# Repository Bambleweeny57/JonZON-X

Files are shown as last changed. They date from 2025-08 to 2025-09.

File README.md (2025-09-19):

# 🎵 JonZON-X AY-3-8910 Sound Expansion for ZX81

JonZON-X is a modern recreation of the ZON-X-81 Sound Box by Bi-Pak, designed for the ZX81. It uses the AY-3-8910 Programmable Sound Generator (PSG) and supports stereo line-out, optional multi-PSG expansion, and historically accurate address decoding.

This project prioritizes:
- ✅ Robust signal integrity
- ✅ Accurate control logic
- ✅ Modular expansion
- ✅ Historical preservation

---

## 🎯 Goals

- Recreate the original ZON-X-81 using AY-3-8910 (not AY-3-8912)
- Provide stereo line-out instead of onboard speaker
- Divide CPU clock as in the original design
- Support optional second and third PSGs via A5 and A6
- Document logic blocks and truth tables that match the actual schematic

---

## 🧠 Control Signal Logic

JonZON-X uses modern 74HC-series gates to derive control signals for the AY-3-8910. The address decoding is based on:

- **A0–A4**: Select the first PSG
- **A5**: Optional second PSG (replaces A4)
- **A6**: Optional third PSG (replaces A4)
- **A7**: Used in BC1 logic
- **/IOREQ**, **/WR**, **/RD**: Control timing

### Signal Derivation

| Signal | Logic Expression | Gates Used |
|---|---|---|
| **BDIR** | Derived from /IOREQ and /WR  
→ Routed through 74HC02 (inversion), 74HC08 (AND), and 74HC11 (3-input AND) | 74HC02, 74HC08, 74HC11 |
| **BC1** | Derived from /IOREQ, /WR, A2, A7, /RD  
→ Routed through 74HC02, 74HC08, and 74HC11 | 74HC02, 74HC08, 74HC11 |

There is **no AYSEL signal**—address selection is handled directly via A0–A4 (or A5/A6 for additional PSGs).

---

## 📊 Truth Table

| A0–A4 | A5/A6 | A2 | A7 | /IOREQ | /WR | /RD | BDIR | BC1 | Operation |
|---|---|----|----|---|-----|-----|---|-----|---|
| PSG 1 selected | — | 1  | 1  | 0 | 0 | 1 | 1 | 1 | Write to register |
| PSG 1 selected | — | 1  | 1  | 0 | 0 | 0 | 1 | 0 | Write to PSG |
| PSG 1 selected | — | 1  | 1  | 0 | 1 | 0 | 0 | 1 | Read from PSG |
| PSG 2 selected | A5=1  | 1  | 1  | 0 | — | — | — | — | Optional second PSG |
| PSG 3 selected | A6=1  | 1  | 1  | 0 | — | — | — | — | Optional third PSG |
| Not selected | — | —  | —  | — | — | — | 0 | 0 | Inactive |

---

## 🖼️ Visual Decode Logic

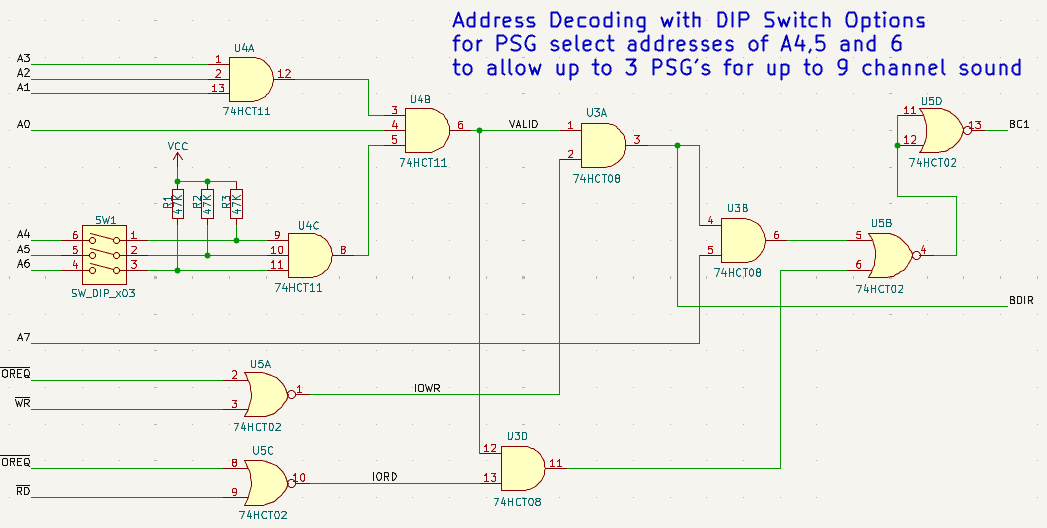
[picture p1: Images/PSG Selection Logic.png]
AY Control Logic


This schematic snippet shows how BDIR and BC1 are generated using 74HC02, 74HC08, and 74HC11 gates. Address selection is handled via A0–A4 (or A5/A6 for additional PSGs).

---

## 🎚️ DIP Switch Mapping for PSG Selection

JonZON-X supports up to three AY-3-8910 PSGs using configurable address lines via DIP switches. The DIP switches control A4, A5, and A6 to select which PSG is active.

| PSG | A4 | A5 | A6 | Address (Binary) | Address (Decimal) |
|---|----|----|----|---|---|
| PSG1  | 1  | 0  | 0  | `11111111` | 255 |
| PSG2  | 0  | 1  | 0  | `11101111` | 239 |
| PSG3  | 0  | 0  | 1  | `11011111` | 223 |

- **A4, A5, A6** are mutually exclusive: only one should be active at a time.
- These bits are part of the PSG register select address.
- DIP switches override the default A4–A6 lines from the ZX81.

This mapping allows users to select which PSG responds to register writes, enabling multi-chip expansion and stereo mixing.

---

## 📚 Historical References

- [ZON-X-81 Archive (1982 Bi-Pak)](https://archive.org/details/ZON_X-81_1982_Bi-Pak_GB)
- [RevSpace ZX81 PSG Expansion](https://revspace.nl/Zon_ZX-81_Programmable_Sound_Generator_expansion_for_ZX81PLUS35_with_working_SD-Card)
- [Mahjongg2 ZON-Compatible PSG](https://github.com/mahjongg2/ZON-compatible-PSG-with-SD-interface-for-ZX81plus35-ZX81)
- [Micromusic Article](https://www.muzines.co.uk/articles/micromusic/4456)
- [ZX8081 Clone Log](https://hackaday.io/project/184361-zx8081-homebrew-clone/log/203915-my-project-log-jan-mar2021)

---

## 🛠️ Future Plans

If the initial revision works, future additions may include:
- RAM and ROM expansion
- Joystick port
- Enhanced stereo mixing

---

### 🧪 Test 1: Test Routine

```basic
10 REM ZONTEST1
20 LET A=16514
30 POKE A,62
40 LET A=A+1
50 POKE A,0
60 LET A=A+1
70 POKE A,211
80 LET A=A+1
90 POKE A,0
100 LET A=A+1
110 POKE A,201
120 POKE 16515,7
130 POKE 16516,255
140 RAND USR 16514
150 POKE 16515,8
160 POKE 16516,191
170 RAND USR 16514
180 POKE 16515,13
190 POKE 16516,9
200 RAND USR 16514
210 GOTO 210
```
- 🔊 ZONTEST1 – Basic Tone Setup: [zontest1.p](https://github.com/jgratton72/JonZON-X/blob/master/Tests/zontest1.p)

### 🧪 Test 2: Envelope & Stereo Test

```basic
10 REM ZONTEST2
20 LET A=16514
30 POKE A,62
40 LET A=A+1
50 POKE A,0
60 LET A=A+1
70 POKE A,211
80 LET A=A+1
90 POKE A,0
100 LET A=A+1
110 POKE A,201
120 POKE 16515,7
130 POKE 16516,255
140 RAND USR 16514
150 POKE 16515,8
160 POKE 16516,191
170 RAND USR 16514
180 POKE 16515,13
190 POKE 16516,9
200 RAND USR 16514
210 LET E=0
220 POKE 16515,13
230 POKE 16516,E
240 RAND USR 16514
250 LET I=0
260 LET I=I+1
270 IF I<1000 THEN GOTO 260
280 LET E=E+1
290 IF E<16 THEN GOTO 220
300 GOTO 210
```
- 🎛️ ZONTEST2 – Envelope & Stereo: [zontest2.p](https://github.com/jgratton72/JonZON-X/blob/master/Tests/zontest2.p)

### 🧪 Test 3: Envelope Period Sweep

```basic
10 REM ZONTEST3
20 LET A=16514
30 POKE A,62
40 LET A=A+1
50 POKE A,0
60 LET A=A+1
70 POKE A,211
80 LET A=A+1
90 POKE A,0
100 LET A=A+1
110 POKE A,201
120 POKE 16515,7
130 POKE 16516,255
140 RAND USR 16514
150 POKE 16515,8
160 POKE 16516,191
170 RAND USR 16514
180 POKE 16515,13
190 POKE 16516,9
200 RAND USR 16514
210 LET P=0
220 POKE 16515,11
230 POKE 16516,P
240 RAND USR 16514
250 POKE 16515,12
260 POKE 16516,0
270 RAND USR 16514
280 LET I=0
290 LET I=I+1
300 IF I<1000 THEN GOTO 290
310 LET P=P+16
320 IF P<256 THEN GOTO 220
330 GOTO 210
```
- 📈 ZONTEST3 – Envelope Sweep: [zontest3.p](https://github.com/jgratton72/JonZON-X/blob/master/Tests/zontest3.p)

### 🧪 Test 4: DIP-Selectable PSG Verification

```basic
10 REM ZONTEST4
20 LET A=16514
30 POKE A,62
40 LET A=A+1
50 POKE A,0
60 LET A=A+1
70 POKE A,211
80 LET A=A+1
90 POKE A,0
100 LET A=A+1
110 POKE A,201
120 POKE 16515,8
130 POKE 16516,255
140 RAND USR 16514
150 LET I=0
160 LET I=I+1
170 IF I<500 THEN GOTO 160
180 POKE 16515,8
190 POKE 16516,239
200 RAND USR 16514
210 LET I=0
220 LET I=I+1
230 IF I<500 THEN GOTO 220
240 POKE 16515,8
250 POKE 16516,223
260 RAND USR 16514
270 LET I=0
280 LET I=I+1
290 IF I<500 THEN GOTO 280
300 GOTO 120
```
- 🎚️ ZONTEST4 – DIP-Selectable PSGs: [zontest4.p](https://github.com/jgratton72/JonZON-X/blob/master/Tests/zontest4.p)

---

## 📅 Revision History

### 🔧 Rev 1.0 Testing Note — Stereo Jack Adaptation
- **Socket Type:** 3-pin stereo jacks used in place of shunted 5-pin variants.
- **Pad Bridging:** Inner pads manually jumped to outer signal pads; ground positioned at center front.
- **Trade-off:** Left and Right channels will be reversed — acceptable for initial validation.
- **Rationale:** Simplifies early testing without requiring shunt headers. Prioritizes proof-of-function over stereo fidelity

### 🔄 Rev 1.1 — Audio Jack Correction
- **Issue:** Left and Right channels were misrouted via Shunts A and B.
- **Fix:** Channel A and B were reversed in the schematic to compensate for the physical swap.
- **Impact:** Stereo output now matches expected channel mapping. Updated KiCad files reflect this correction.

### 🔄 Rev 1.2 – Stereo Output Mapping Adjustment

- **Issue**: Legacy ZON-X-81 software frequently routes noise to Channel B, but JonZON-X previously mixed Channel C to both outputs (a common pattern in other PSG devices, including the ZX Spectrum 128K). This caused noise effects to be isolated to the right channel or lost in stereo playback.
- **Fix**: Remapped stereo output:
  - Channel A → Left
  - Channel B → Mixed (Left + Right)
  - Channel C → Right  
  This ensures Channel B (the legacy noise channel) is centered in stereo output.
- **Impact**: Improved compatibility with original ZON-X-81 programs and demos. Noise effects now play as intended across both channels, preserving the sonic balance of legacy software.

[]()

### 🔄 Rev 1.3 – Logic Footprint Correction
- **Issue**: 74HTC Logic IC footprints where set as 400mil wide not 300mil.
- **Fix**: Change footprints:
  - Corrected 74HCT logic IC footprints from 400mil to 300mil for proper socket fit.
  - Updated KiCad symbols and PCB layout to reflect accurate DIP sizing.
- **Impact**: Improves build reliability and simplifies future revisions.

### 🔄 Rev 1.4 – Dual PSG Support & Expansion-Ready Logic

- 🧩 **Added AY-3-8912 schematic symbol** to Rev 1.3 base, enabling direct support for legacy demos and stereo output
- 🧠 **Dual PSG compatibility**: Supports both AY-3-8910 and AY-3-8912 via shared footprint and modular decoding logic
- 🧰 **Decoding logic updated** to include `/RD` line—reserved for future expansion (e.g. SD card interfacing via Port A)
- 🛠️ **Maintains Rev 1.3 write logic** for AY-3-8910 while enabling seamless upgrade path to AY-3-8912
- 🎶 **Verified compatibility** with original ULA and both HCT and F-series logic—multi scroll and Viaduct demos pass cleanly with AY-3-8912
- ⚠️ **VLA81 compatibility issues noted**: Viaduct demo fails to run reliably due to timing sensitivity and address decoding quirks. Detaching A15 improves behavior in some cases but does not fully resolve playback issues. Original ULA remains the recommended option for stable demo performance.
- 📘 **README and onboarding overlays updated** to reflect dual-chip support and future expansion notes

[]()

> Rev 1.4 preserves the modular ethos of JonZON-X while enabling legacy fidelity and future-proofed decoding. Component back-mounting and through-hole edge connector support are planned for a future revision.

---

## 🧩 Rev1.x Closure Summary

The Rev1.x series of JONZON-X-81 boards concludes with **Rev1.4**, marking the final iteration of this foundational phase. Throughout development, multiple configurations were explored to optimize PSG register selection and compatibility:

- **AY-3-8910** with grounded Port B showed partial success in register selection, but inconsistencies remained—especially when paired with **74F logic**.
- Transitioning to **AY-3-8912** and **74HCT logic** yielded flawless register selection across demo routines, confirming a stable configuration.

Based on these findings, Rev1.4 is the final release in the Rev1.x lineage. All future development will pivot to **Rev2.0**, which will:

- Standardize on the **AY-3-8912** sound chip.
- Feature **back-mounted components** for cleaner top-side access.
- Introduce a **through-hole edge connector** to support future expansions.
- Include a **development header** exposing A0–A7, 5V, and GND—enabling both sound card interfacing and SD card experimentation via Port A.

Documentation for Rev1.x will remain available for reference and legacy compatibility. Contributors are encouraged to migrate to the Rev2.0 repo for ongoing development and community collaboration.

---

## 📝 Notes

This is my first KiCad project and GitHub repo. While I’ve used other EDA tools and GitHub before, this is a learning curve and a preservation effort.

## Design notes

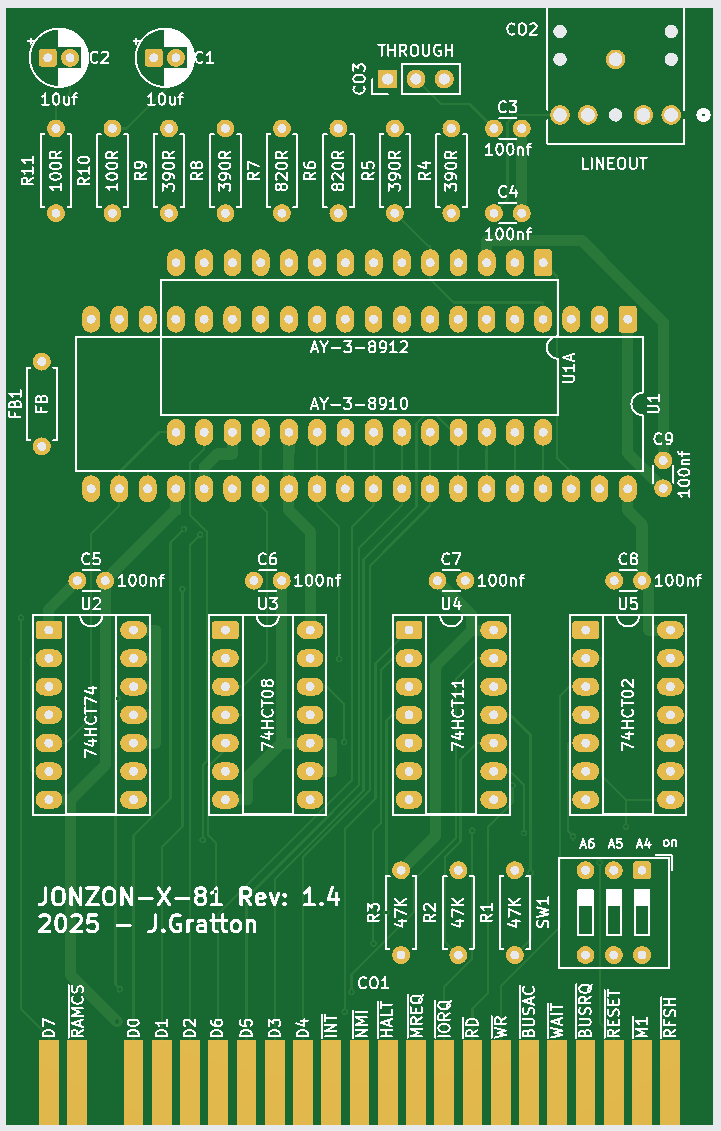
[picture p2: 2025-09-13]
Images/Gerber Top.png

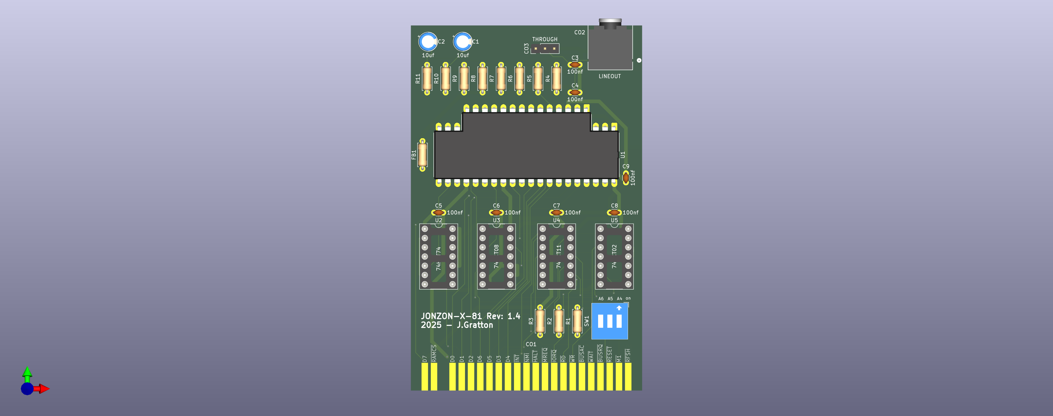
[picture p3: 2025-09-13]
Images/MyZON-X Top.png

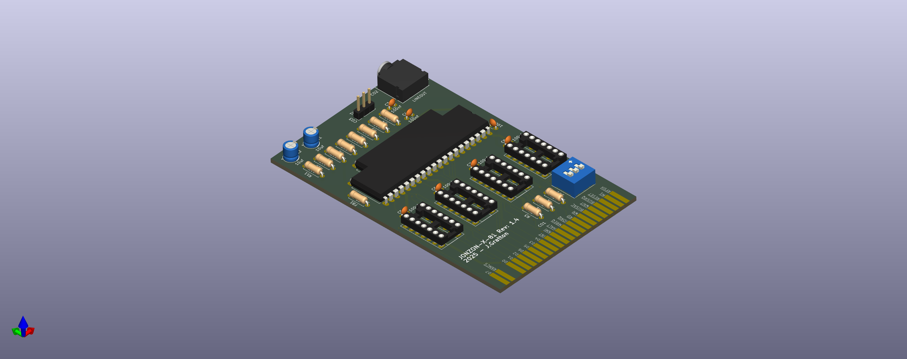
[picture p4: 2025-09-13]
Images/JONZON-X-81 Angled.png

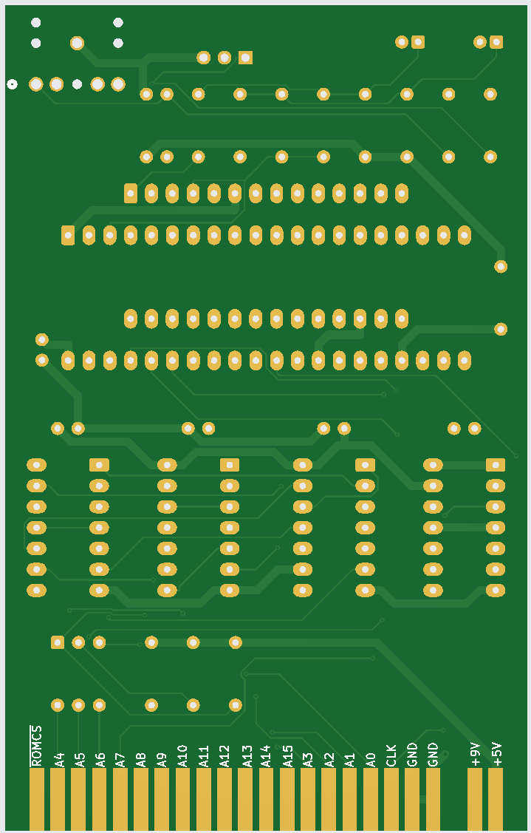
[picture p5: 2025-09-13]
Images/Gerber Bottom.png

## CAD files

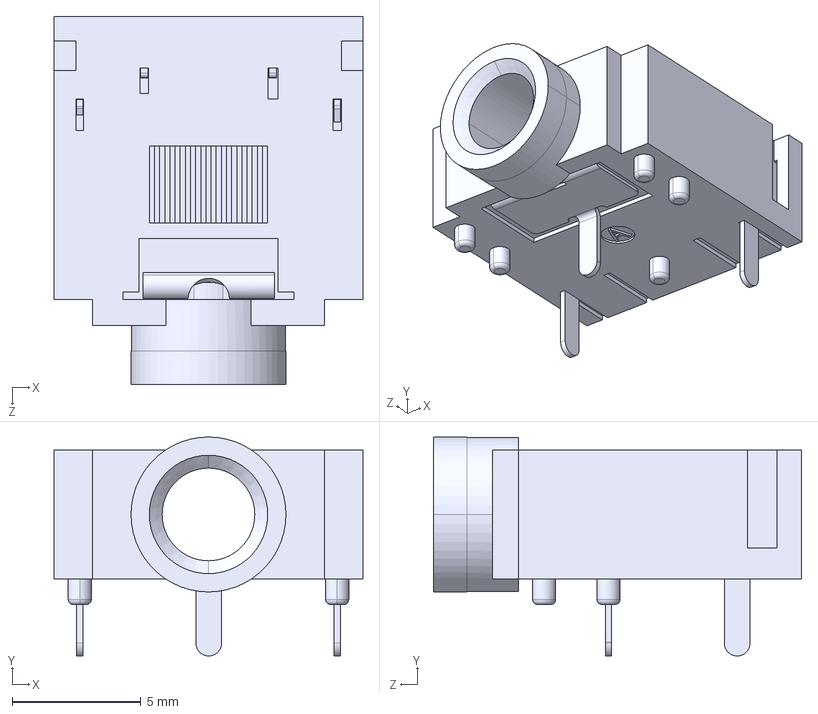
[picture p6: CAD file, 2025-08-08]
Stereo Jack/SJ1-3523N--3DModel-STEP-1.STEP
12.0 x 8.51 x 14.3 mm

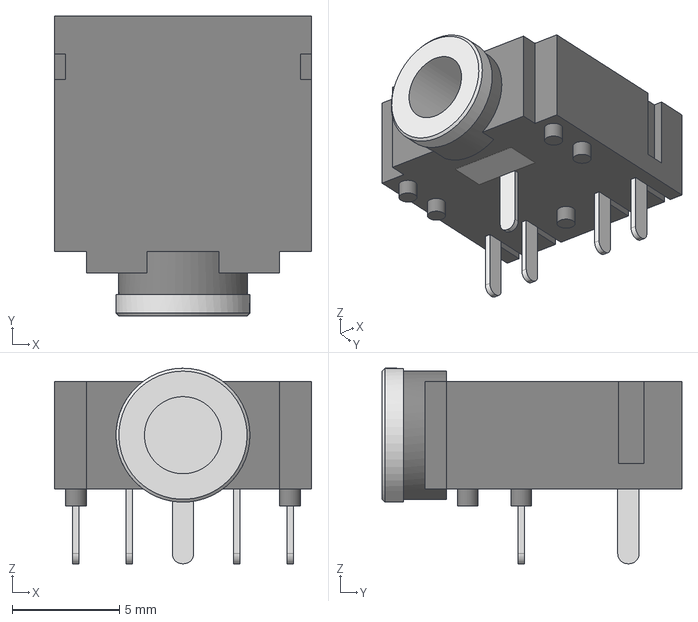
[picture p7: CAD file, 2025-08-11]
Stereo Jack/SPC21348.stp
12.0 x 14.0 x 9.13 mm

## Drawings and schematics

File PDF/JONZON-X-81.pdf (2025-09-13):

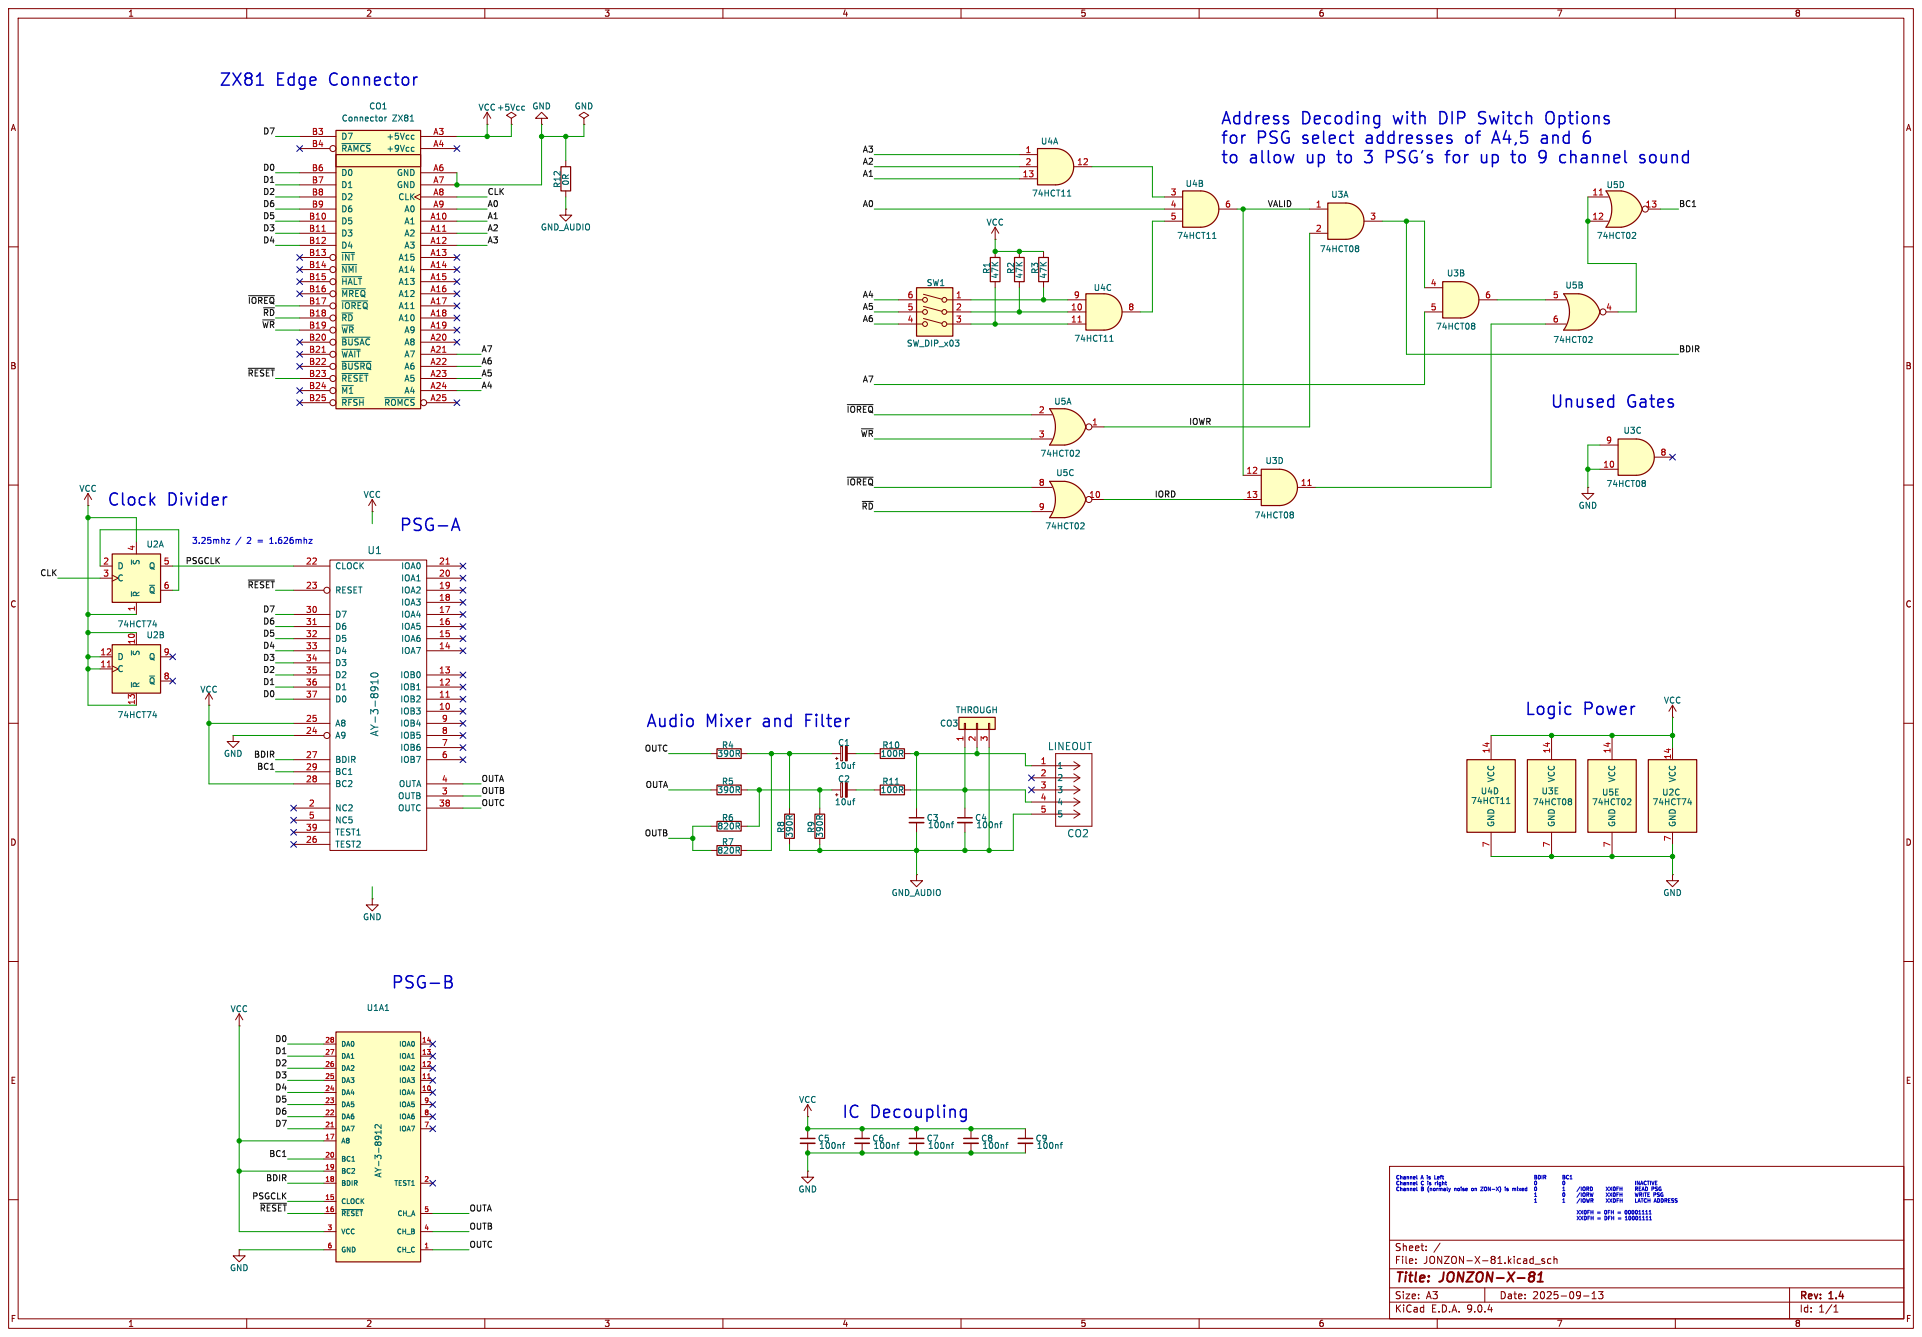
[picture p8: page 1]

Address Decoding with DIP Switch Options
to allow up to 3 PSG's for up to 9 channel sound

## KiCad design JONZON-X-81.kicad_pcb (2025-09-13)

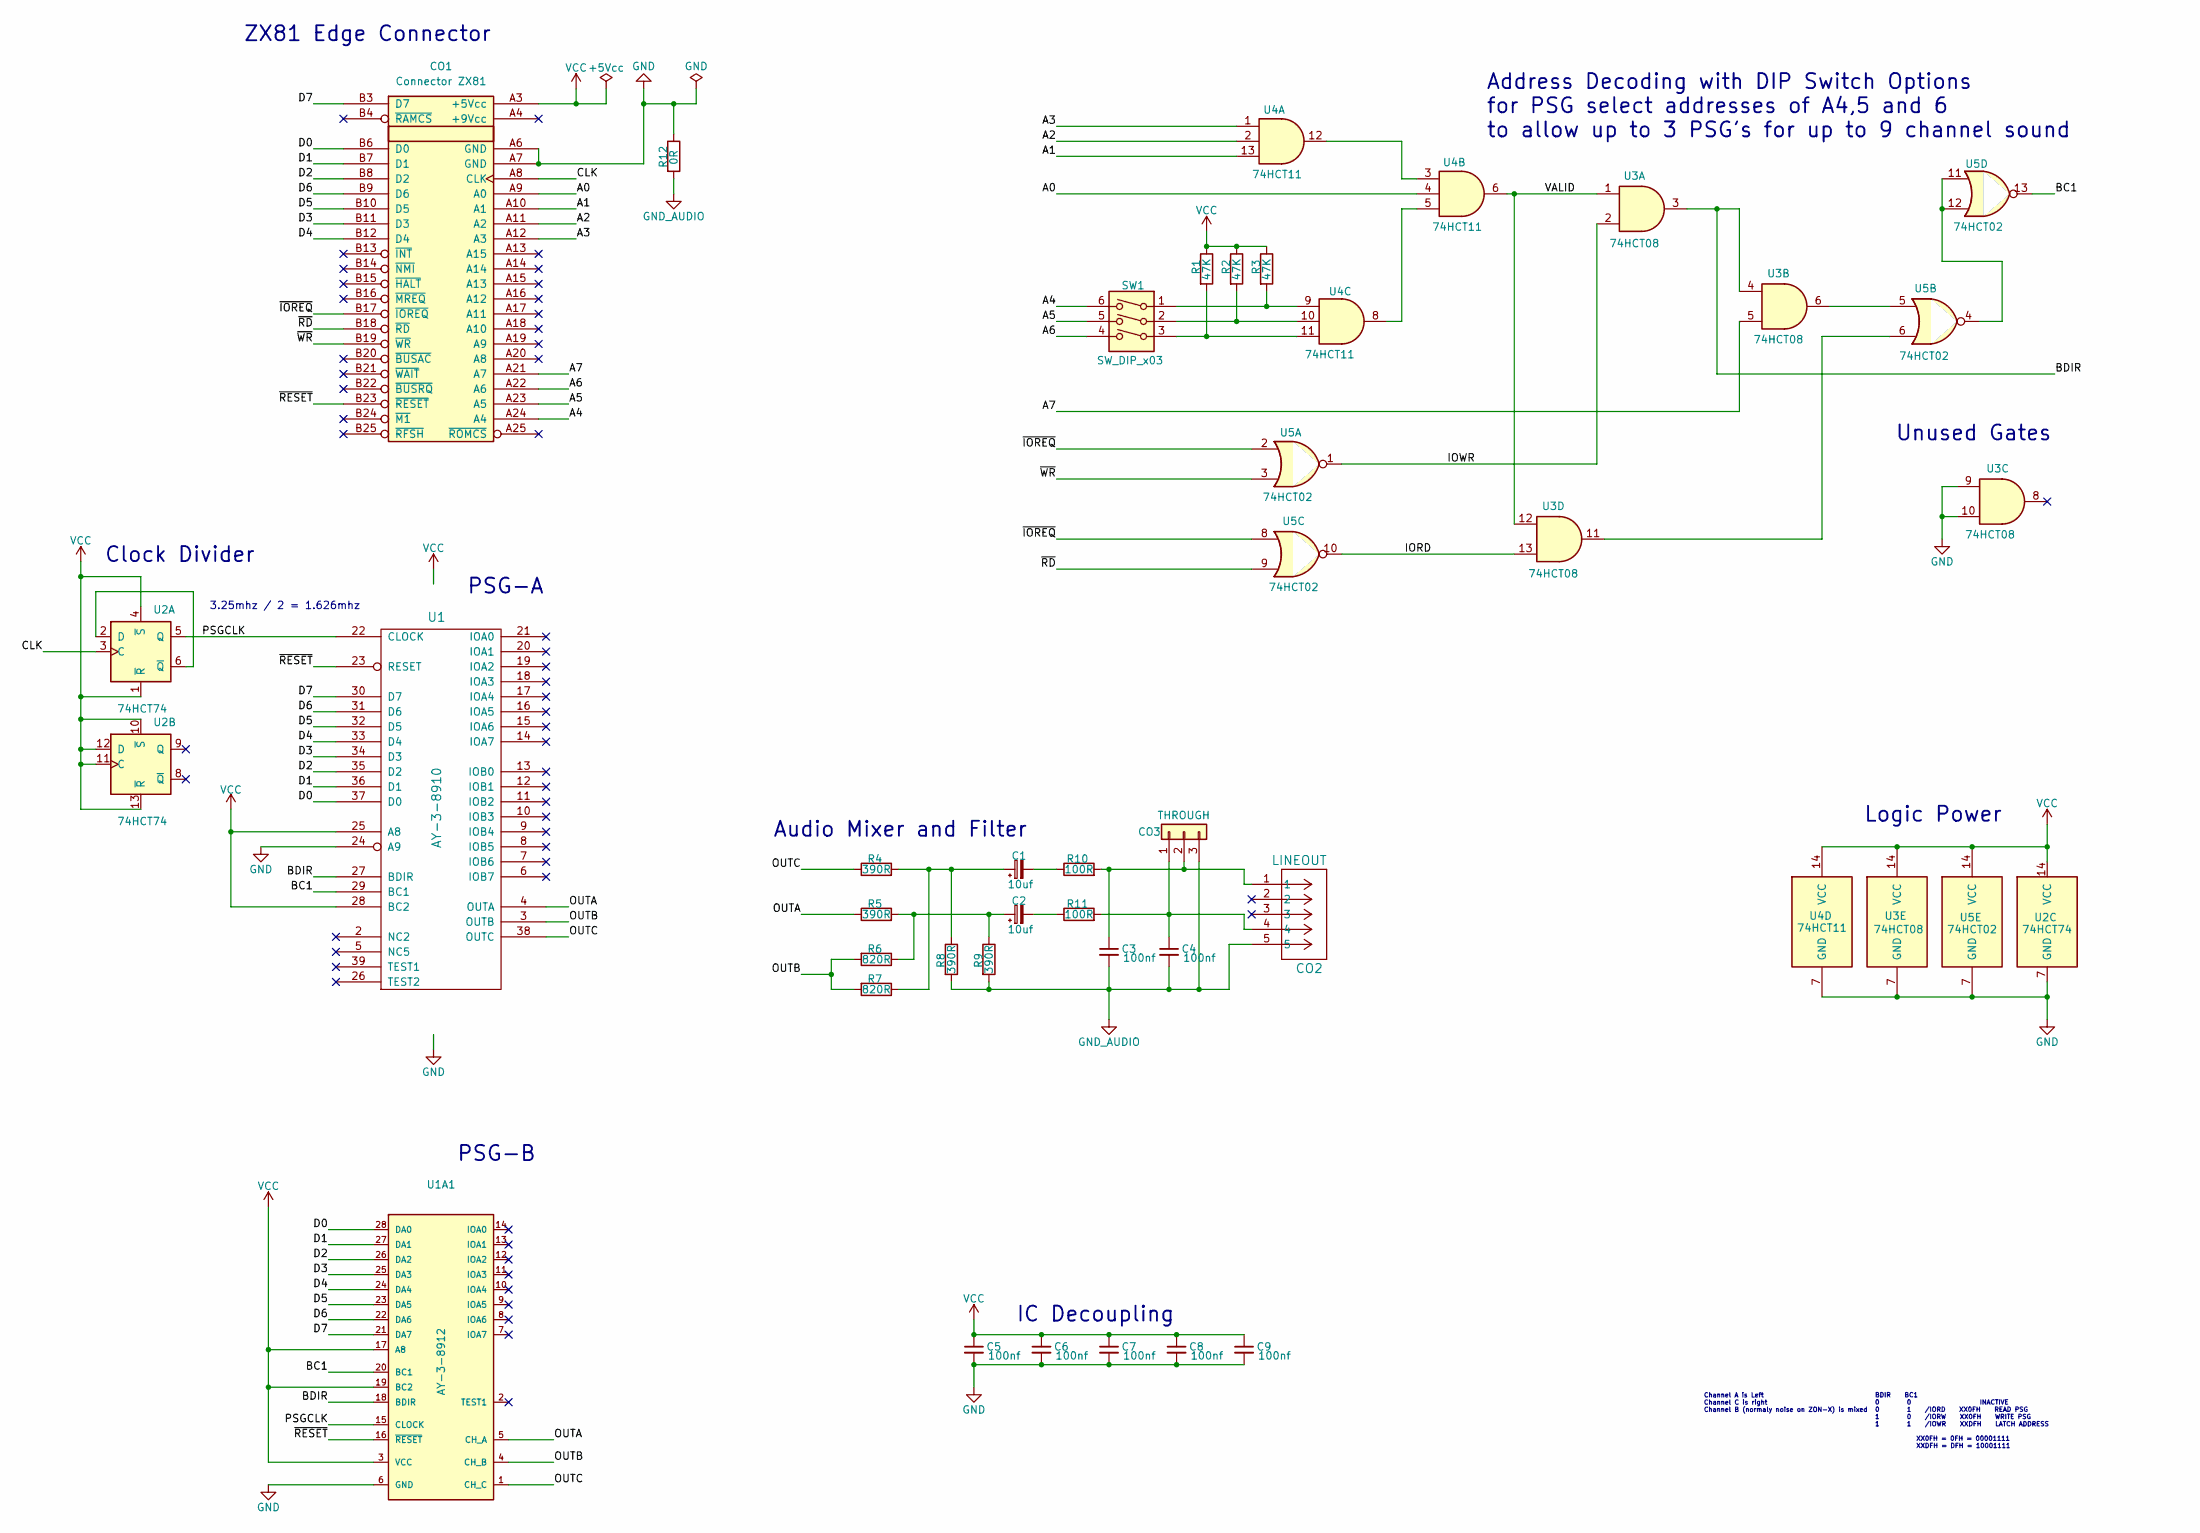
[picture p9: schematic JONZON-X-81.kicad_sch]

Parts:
C1, C2: 10uf; CP_Radial_D5.0mm_P2.00mm
C3, C4, C5, C6, C7, C8, C9: 100nf; C_Disc_D3.0mm_W1.6mm_P2.50mm
CO1: Connector ZX81; EDGE ZX81 TOP
CO2: LINEOUT; CONN5_SPC21348_MTC
CO3: THROUGH; PinHeader_1x03_P2.54mm_Vertical
R1, R2, R3: 47K; R_Axial_DIN0207_L6.3mm_D2.5mm_P7.62mm_Horizontal
R4, R5, R8, R9: 390R; R_Axial_DIN0207_L6.3mm_D2.5mm_P7.62mm_Horizontal
R6, R7: 820R; R_Axial_DIN0207_L6.3mm_D2.5mm_P7.62mm_Horizontal
R10, R11: 100R; R_Axial_DIN0207_L6.3mm_D2.5mm_P7.62mm_Horizontal
R12: 0R; R_Axial_DIN0207_L6.3mm_D2.5mm_P7.62mm_Horizontal
SW1: SW_DIP_x03; SW_DIP_SPSTx03_Slide_9.78x9.8mm_W7.62mm_P2.54mm
U1: AY-3-8910; DIP-40_W15.24mm_LongPads
U1A1: AY-3-8912; DIP-28_W15.24mm_LongPads
U2: 74HCT74; DIP-14_W7.62mm_Socket_LongPads
U3: 74HCT08; DIP-14_W7.62mm_Socket_LongPads
U4: 74HCT11; DIP-14_W7.62mm_Socket_LongPads
U5: 74HCT02; DIP-14_W7.62mm_Socket_LongPads

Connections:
/A0: CO1.A9 (A0), U4.4
/A1: CO1.A10 (A1), U4.13
/A2: CO1.A11 (A2), U4.2
/A3: CO1.A12 (A3), U4.1
/A4: CO1.A24 (A4), SW1.6
/A5: CO1.A23 (A5), SW1.5
/A6: CO1.A22 (A6), SW1.4
/A7: CO1.A21 (A7), U3.5
/BC1: U1.29 (BC1), U1A1.20 (BC1), U5.13; also elsewhere on the board
/BDIR: U1.27 (BDIR), U1A1.18 (BDIR), U3.3, U3.4; also elsewhere on the board
/CLK: CO1.A8 (CLK), U2.3 (C)
/D0: CO1.B6 (D0), U1.37 (D0), U1A1.28 (DA0); also elsewhere on the board
/D1: CO1.B7 (D1), U1.36 (D1), U1A1.27 (DA1); also elsewhere on the board
/D2: CO1.B8 (D2), U1.35 (D2), U1A1.26 (DA2); also elsewhere on the board
/D3: CO1.B11 (D3), U1.34 (D3), U1A1.25 (DA3); also elsewhere on the board
/D4: CO1.B12 (D4), U1.33 (D4), U1A1.24 (DA4); also elsewhere on the board
/D5: CO1.B10 (D5), U1.32 (D5), U1A1.23 (DA5); also elsewhere on the board
/D6: CO1.B9 (D6), U1.31 (D6), U1A1.22 (DA6); also elsewhere on the board
/D7: CO1.B3 (D7), U1.30 (D7), U1A1.21 (DA7); also elsewhere on the board
/IORD: U3.13, U5.10
/IOWR: U3.2, U5.1
/OUTA: R5.1, U1.4 (OUTA), U1A1.5 (CH_A); also elsewhere on the board
/OUTB: R6.2, R7.2, U1.3 (OUTB), U1A1.4 (CH_B); also elsewhere on the board
/OUTC: R4.1, U1.38 (OUTC), U1A1.1 (CH_C); also elsewhere on the board
/PSGCLK: U1.22 (CLOCK), U1A1.15 (CLOCK), U2.5 (Q); also elsewhere on the board
/VALID: U3.1, U3.12, U4.6
/~IOREQ: CO1.B17 (~IOREQ), U5.2, U5.8
/~RD: CO1.B18 (~RD), U5.9
/~RESET: CO1.B23 (~RESET), U1.23 (RESET), U1A1.16 (~RESET); also elsewhere on the board
/~WR: CO1.B19 (~WR), U5.3
GND: C5.2, C6.2, C7.2, C8.2, C9.2, CO1.A6 (GND), CO1.A7 (GND), R12.1, U1.1 (GND), U1.24 (A9), U1A1.6 (GND), U2.7 (GND), U3.7 (GND), U3.9, U3.10, U4.7 (GND), U5.7 (GND); also elsewhere on the board
GND_AUDIO: C3.2, C4.2, CO2.5, CO3.3, R8.2, R9.2, R12.2; also elsewhere on the board
unnamed: C1.1, R4.2, R7.1, R8.1
unnamed: C1.2, R10.1
unnamed: C2.1, R5.2, R6.1, R9.1
unnamed: C2.2, R11.1
unnamed: C4.1, CO2.4, CO3.1, R11.2
unnamed: C3.1, CO2.1, CO3.2, R10.2
unnamed: R1.2, SW1.3, U4.11
unnamed: R2.2, SW1.2, U4.10
unnamed: R3.2, SW1.1, U4.9
unnamed: U2.2 (D), U2.6 (~Q)
unnamed: U3.6, U5.5
unnamed: U3.11, U5.6
unnamed: U4.5, U4.8
unnamed: U4.3, U4.12
unnamed: U5.4, U5.11, U5.12
VCC: C5.1, C6.1, C7.1, C8.1, C9.1, CO1.A3 (+5Vcc), R1.1, R2.1, R3.1, U1.25 (A8), U1.28 (BC2), U1.40 (VCC), U1A1.3 (VCC), U1A1.17 (A8), U1A1.19 (BC2), U2.1 (~R), U2.4 (~S), U2.10 (~S), U2.11 (C), U2.12 (D), U2.13 (~R), U2.14 (VCC), U3.14 (VCC), U4.14 (VCC), U5.14 (VCC); also elsewhere on the board

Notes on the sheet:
Address Decoding with DIP Switch Options for PSG select addresses of A4,5 and 6 to allow up to 3 PSG's for up to 9 channel sound
ZX81 Edge Connector
PSG-A
IC Decoupling
Clock Divider
Logic Power
PSG-B
Unused Gates
BDIR BC1 0 0 INACTIVE 0 1 /IORD XX0FH READ PSG 1 0 /IORW XX0FH WRITE PSG 1 1 /IOWR XXDFH LATCH ADDRESS XX0FH = 0FH = 00001111 XXDFH = DFH = 10001111
Channel A is Left Channel C is right Channel B (normaly noise on ZON-X) is mixed
Audio Mixer and Filter
3.25mhz / 2 = 1.626mhz

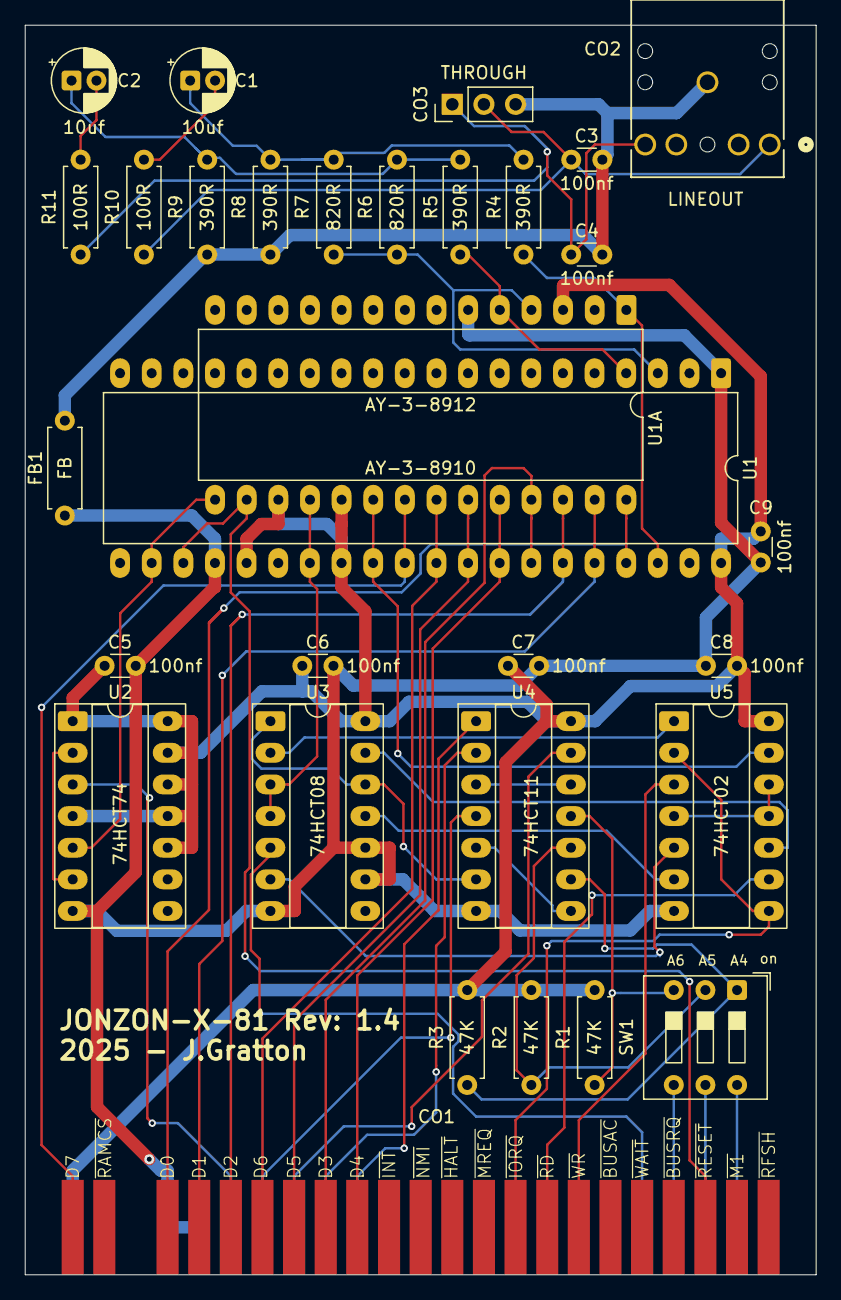
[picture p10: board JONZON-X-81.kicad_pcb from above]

Board: 2 copper layers, 63.5 x 100.3 mm, 31 parts (0 on the bottom side), 48 nets.

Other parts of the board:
FB1: FB; R_Axial_DIN0207_L6.3mm_D2.5mm_P7.62mm_Horizontal
U1A: AY-3-8912; DIP-28_W15.24mm_LongPads

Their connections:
/BC1: U1A.20 (BC1); also elsewhere on the board
/BDIR: U1A.18 (BDIR); also elsewhere on the board
/D0: U1A.28 (DA0); also elsewhere on the board
/D1: U1A.27 (DA1); also elsewhere on the board
/D2: U1A.26 (DA2); also elsewhere on the board
/D3: U1A.25 (DA3); also elsewhere on the board
/D4: U1A.24 (DA4); also elsewhere on the board
/D5: U1A.23 (DA5); also elsewhere on the board
/D6: U1A.22 (DA6); also elsewhere on the board
/D7: U1A.21 (DA7); also elsewhere on the board
/OUTA: U1A.5 (CH_A); also elsewhere on the board
/OUTB: U1A.4 (CH_B); also elsewhere on the board
/OUTC: U1A.1 (CH_C); also elsewhere on the board
/PSGCLK: U1A.15 (CLOCK); also elsewhere on the board
/~RESET: U1A.16 (~RESET); also elsewhere on the board
GND: FB1.1, U1A.6 (GND); also elsewhere on the board
GND_AUDIO: FB1.2; also elsewhere on the board
VCC: U1A.3 (VCC), U1A.17 (A8), U1A.19 (BC2); also elsewhere on the board

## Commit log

2025-08-01 change 1
    [MyZON-X.kicad_sch]
2025-08-01 commit 2
    [MyZON-X.kicad_sch]
2025-08-01 commit 3
    [MyZON-X.kicad_sch]
2025-08-01 commit 4
    [MyZON-X.kicad_sch]
2025-08-01 added clock
    [MyZON-X.kicad_sch]
2025-08-02 Added new ZX81 Edge Connector and Decoupling
    [MyZON-X.kicad_sch]
2025-08-03 Added podt coupling output filtering
    [MyZON-X.kicad_sch]
2025-08-03 realigened autio out stage
    [MyZON-X.kicad_sch]
2025-08-04 A7 was missaligned Added text to show detail of channel mixing on audio
    [MyZON-X.kicad_sch]
2025-08-05 Added Audio interconnect Added extra nots for Addressing
    [MyZON-X.kicad_sch]
2025-08-06 Added VCC and GND Added Power Suuply to IC's Commented 3 ERC warnings re bidirectional pins for 5v and GND for the ZX81 Connector
    [MyZON-X.kicad_sch]
2025-08-06 Channged Channel A and B over on the audio mixer as they would have been the wrong way to what I intended.
    [MyZON-X.kicad_sch]
2025-08-06 updated schematic pdf
2025-08-08 added just two power inputs for +5Vcc to VCC and GND to GND Created commented ERC warning as +5Vcc and GND are bidirectional by design. Move a few of the text comments to make the schematic look neat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
    [MyZON-X.kicad_sch]
2025-08-08 Started PCB
    [MyZON-X.kicad_pcb, MyZON-X.kicad_sch]
2025-08-08 Added Auto Jack Added Board outline Layed out some components in Board outline
    [MyZON-X.kicad_pcb, MyZON-X.kicad_sch, SJ1-3523N--3DModel-STEP-1.STEP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]
2025-08-11 Routed PCB first pass Updated footprint for Audio Line Out Jack Added 3D model for Audio Line Out Jack Updated Schematic PDF Updated 3D Image
    [MyZON-X - PreRoute.kicad_pcb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]
2025-08-11 Added Fab Files Added Revision to PCB
    [MyZON-X-B_Cu.gbr, MyZON-X-B_Mask.gbr, MyZON-X-B_Paste.gbr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]
2025-08-11 Tidy up
    [MyZON-X-B_Cu.gbr, MyZON-X-B_Mask.gbr, MyZON-X-B_Paste.gbr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]
2025-08-12 Changed Label on LINEIN to THROUGH Added seperate Ground and Audio Ground Added 0ohm link for Ground to Audio Ground link Could be a Ferrite Bead
    [MyZON-X-B_Cu.gbr, MyZON-X-B_Mask.gbr, MyZON-X-B_Paste.gbr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]
2025-08-12 upade 3D model of PCB
2025-08-12 Update Design Check on PCB
2025-08-12 Renamed files Added Ground and Audio Ground Planes Moved Ground Bridge to be between ground planes Generated some new images
    [JONZON-X-81-B_Cu.gbr, JONZON-X-81-B_Mask.gbr, JONZON-X-81-B_Paste.gbr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]
2025-08-12 New fab files
    [JONZON-X-81-B_Cu.gbr, JONZON-X-81-B_Mask.gbr, JONZON-X-81-B_Paste.gbr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]
2025-08-15 Pulled /A9 low
    [JONZON-X-81.kicad_pcb, JONZON-X-81.kicad_sch]
2025-08-15 updated lots of things
    [JONZON-X-81-B_Cu.gbr, JONZON-X-81-B_Mask.gbr, JONZON-X-81-B_Paste.gbr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]
2025-08-16 fenced and stiched ground planes
    [JONZON-X-81-B_Cu.gbr, JONZON-X-81-B_Mask.gbr, JONZON-X-81-B_Paste.gbr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]
2025-08-16 removed fab files
    [JONZON-X-81-B_Cu.gbr, JONZON-X-81-B_Mask.gbr, JONZON-X-81-B_Paste.gbr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]
2025-08-16 built new fab files
    [JONZON-X-81-B_Cu.gbr, JONZON-X-81-B_Mask.gbr, JONZON-X-81-B_Paste.gbr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]
2025-08-16 corrected connections on audio jack as the footprint does not match the schematic symbol pinout. the left and right where on rev 1.0 connected to shunts a and b. to correct this I will just place sho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
    [JONZON-X-81.kicad_pcb, JONZON-X-81.kicad_sch]
2025-08-16 commented rev 1.1 on the PCB
    [JONZON-X-81.kicad_pcb]
2025-08-16 updated rev 1.1 and readme.
    [JONZON-X-81-B_Cu.gbr, JONZON-X-81-B_Mask.gbr, JONZON-X-81-B_Paste.gbr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]
2025-08-25 added rev 1.3 to revision history.
    [JONZON-X-81.kicad_pcb, JONZON-X-81.kicad_sch]
2025-08-25 created new rev 1.3 fab files. updated gerber view images to rev 1.3. removed older revision fab files.
    [JONZON-X-81-B_Cu.gbr, JONZON-X-81-B_Mask.gbr, JONZON-X-81-B_Paste.gbr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]
2025-08-25 change routing on d6
    [JONZON-X-81-B_Cu.gbr, JONZON-X-81-B_Mask.gbr, JONZON-X-81-B_Paste.gbr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]
2025-08-25 updated left channel route.
    [JONZON-X-81-B_Cu.gbr, JONZON-X-81-B_Mask.gbr, JONZON-X-81-B_Paste.gbr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]
2025-09-05 Archiving Project at v1.3 Starting a fresh as a v2.0 with simplified logic.
    [JONZON-X-81-B_Cu.gbr, JONZON-X-81-B_Mask.gbr, JONZON-X-81-B_Paste.gbr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]
2025-09-05 V2.0 start
    [JONZON-X-81.kicad_pcb, JONZON-X-81.kicad_sch]
2025-09-06 built rev2.0 schematic pdf
    [JONZON-X-81.kicad_sch]
2025-09-11 rev 1.3
    [JONZON-X-81-B_Cu.gbr, JONZON-X-81-B_Mask.gbr, JONZON-X-81-B_Paste.gbr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]
2025-09-13 Added AY-3-8912 as an optional PSG to the Schematic. Created new v1.4 PDF.
    [JONZON-X-81.kicad_sch]
2025-09-13 Created rev 1.4 Fab File and Images
    [JONZON-X-81-B_Cu.gbr, JONZON-X-81-B_Mask.gbr, JONZON-X-81-B_Paste.gbr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]
